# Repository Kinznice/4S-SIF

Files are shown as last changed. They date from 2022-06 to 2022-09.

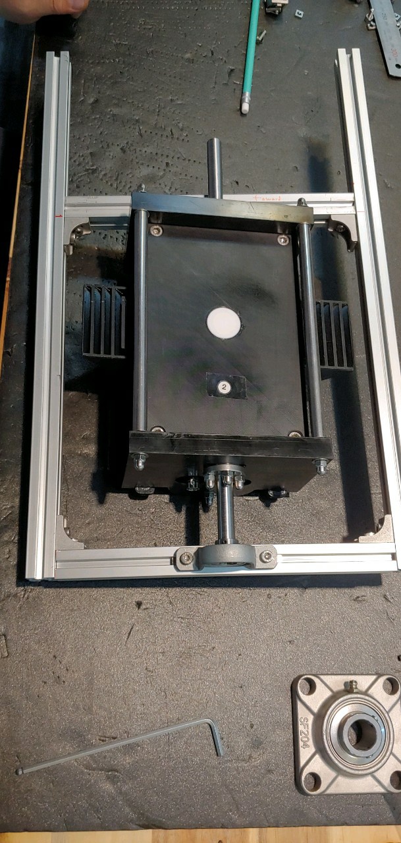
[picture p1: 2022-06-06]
Images/c10.jpg

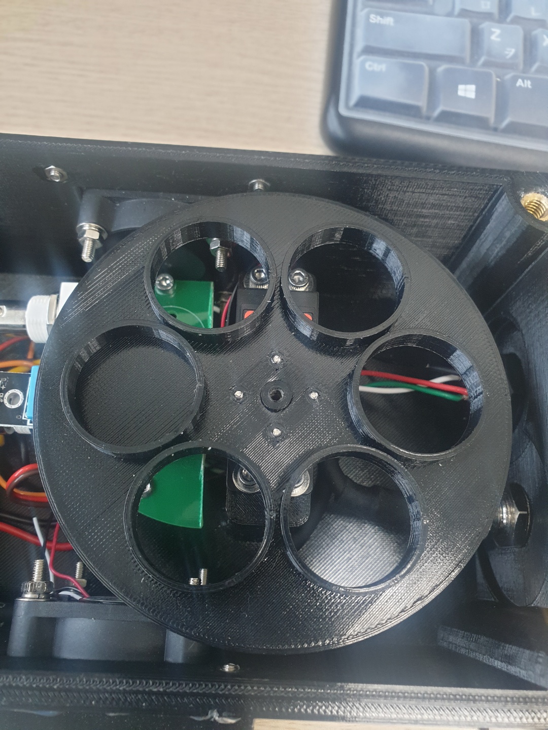
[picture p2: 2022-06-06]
Images/c11.jpg

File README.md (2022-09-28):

# Smart Surface Sensing System - for SIF version (4S-SIF)<br />
% The uploaded information for 4S-SIF.<br />

% Reference: Kim et al., XXXX % <br />

Components > Item Information<br />
3D_printer  > 3D printing Information<br />
Codes > Codes for Raspberry Pi<br />
Images > Images for 4S-SIF<br />
PCB > Customized Printed Circuit Board<br />
4S-SIF code > information about 4S code<br />

/////////////////////////////////////////////////////////////<br />
Contact information:<br /><br />

Jongmin Kim, Ph.D.<br />

Postdoc, Department of Environmental Sciences<br />
University of Virginia<br />
Clark Hall<br />
he | him | his<br />

E-mail : kinznice@gmail.com or JongminKim@virginia.edu<br />
Homepage : www.kimhyodong.com<br />
phone : 1-434-956-9619<br />

/////////////////////////////////////////////////////////////<br />

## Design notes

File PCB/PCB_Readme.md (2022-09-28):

**PCB for 4S-SIF** <br />

Please feel free to tell me if you have any questions. <br /> <br />

------------------------<br />
Jongmin Kim, PhD<br />
he | him | his<br />

E-mail : kinznice@gmail.com or JongminKim@virginia.edu<br />
Homepage : www.kimhyodong.com<br />
phone : 1-434-956-9619<br />

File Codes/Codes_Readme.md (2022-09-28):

**Codes for 4S-SIF** <br />

4S_SIF_FINAL.py = Python for Raspberry Pi to operate 4S-SIF. <br /> <br />
real_recent.sh = Shell file for image to take automatically in Raspberry Pi. <br /> <br />
servo = Python for testing servo motor in Raspberry Pi. <br /> <br />

------------------------<br />
Jongmin Kim, PhD<br />
he | him | his<br />

E-mail : kinznice@gmail.com or JongminKim@virginia.edu<br />
Homepage : www.kimhyodong.com<br />
phone : 1-434-956-9619<br />

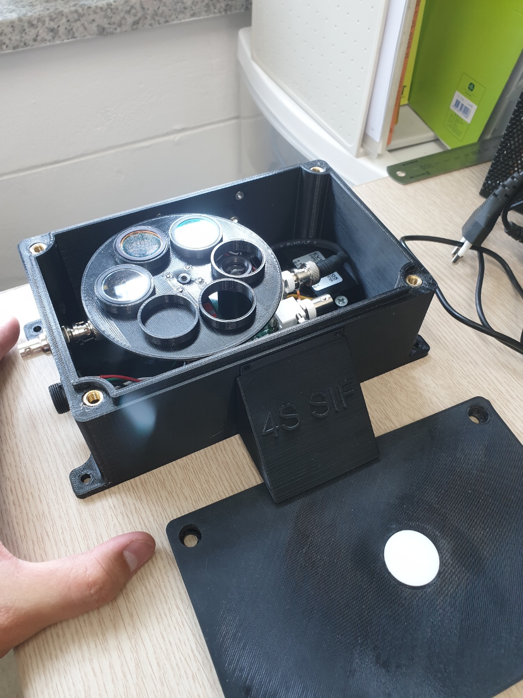
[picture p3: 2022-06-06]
Images/c1.jpg

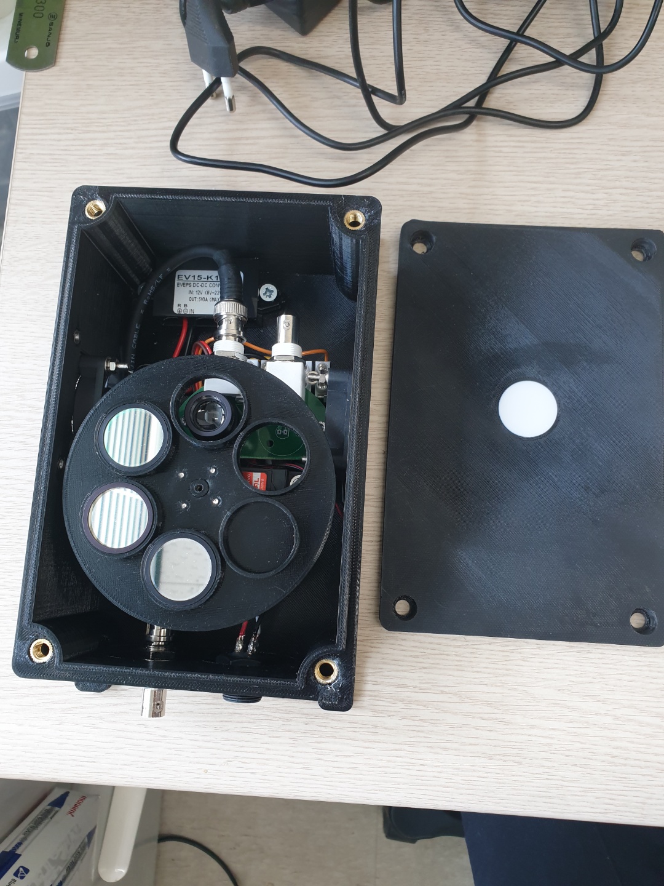
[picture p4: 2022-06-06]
Images/c4.jpg

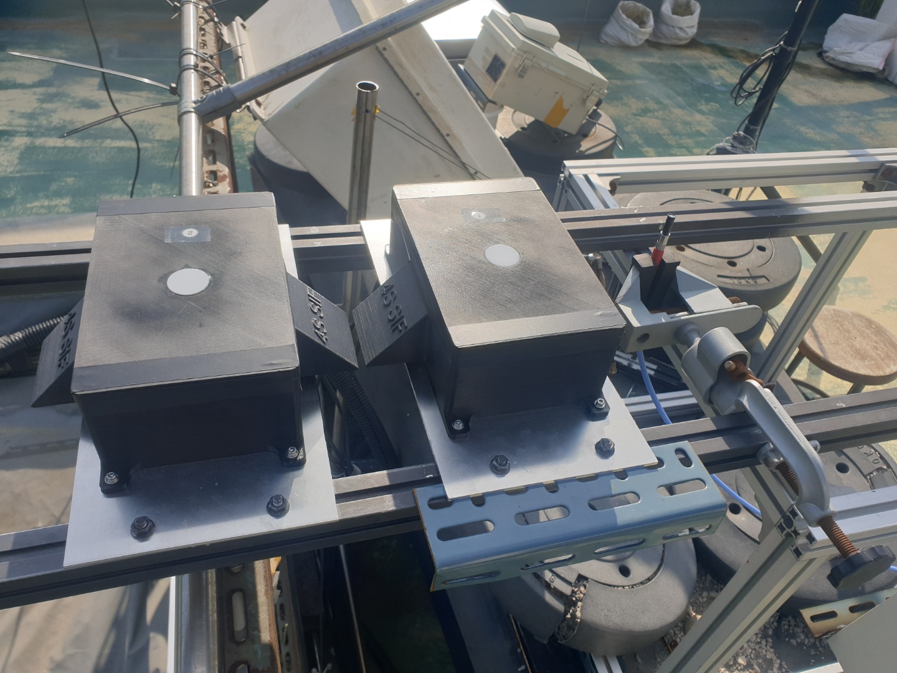
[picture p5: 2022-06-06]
Images/c6.jpg

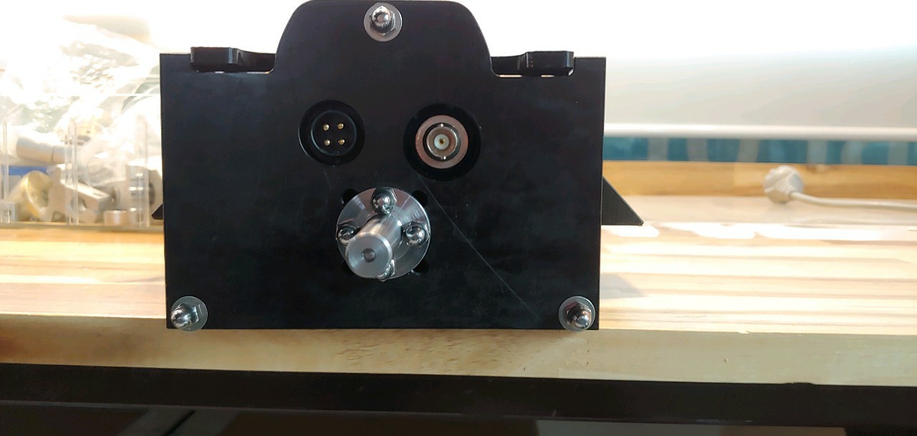
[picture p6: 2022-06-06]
Images/c8.jpg

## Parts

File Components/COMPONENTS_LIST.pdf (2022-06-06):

Appendix. A Components list. Prices as of 2020 - 2021 at South Korea.

Table A1) Components list

Component | Item | Company | Q’ty | Unit price (USD)
Photodiode | S2386-18K | Hamamatsu Photonics | 1 | $ 1.88
Photosensor amplifier | C9329 | Hamamatsu Photonics | 1 | $ 1298
Diffuser | White diffusing glass | Edmund Optics | 1 | $ 43.5
Collimating lens | LA1540-ML | Thorlabs | 1 | $ 38.55
Ultra-narrow bandpass filter for 757 nm | 757.9-1 OD4 | Alluxa | 1 | $ 1160.7
Ultra-narrow bandpass filter for 761 nm | 760.7-1 OD4 | Alluxa | 1 | $ 910
Bandpass filter for 761 nm | 745BP70 | Omega Optical | 1 | $ 409.67
Ultra-narrow bandpass filter for 770 nm | 770NB | Omega Optical | 1 | $ 329
Geared motor | GGM DC 12V 3000rpm | GGM | 1 | $ 49.16
Servomotor | PDI-6225MG-300 | JX | 1 | $ 2.46
Microcomputer | Raspberry Pi b3 module | Raspberry Pi foundation | 1 | $ 41
Temperature and humidity sensor | DHT22 | Adafruit | 1 | $ 0.33
Fan | DC brushless | Jameco electronics | 2 | $ 21.6
Micro SD card 16GB | SD card | Samsung | 1 | $ 17.2
For 3D Structure | PET material | - | 1 | $ 20.5
Sum | | | | $ 4343.55

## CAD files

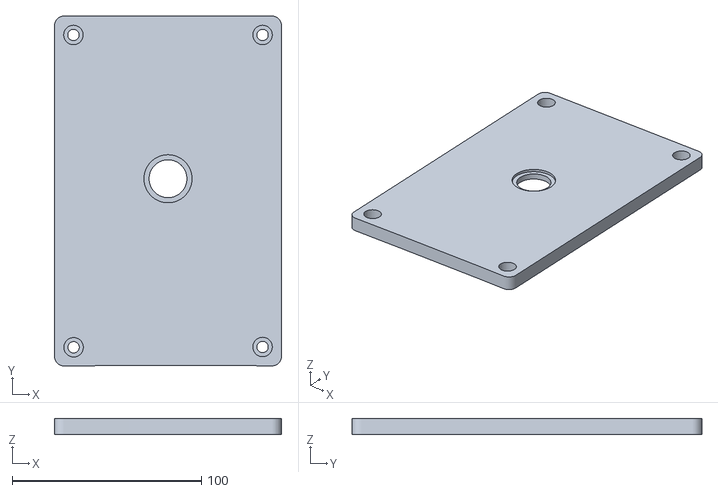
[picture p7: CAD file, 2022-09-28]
3D_printer/Final_V/Main_cap.stl
120.0 x 185.0 x 8.50

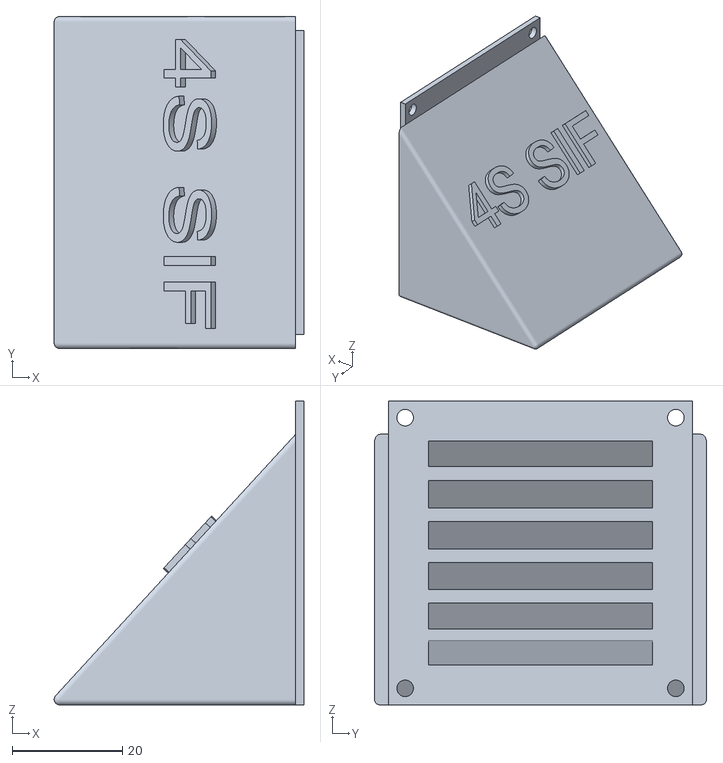
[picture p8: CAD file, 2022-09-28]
3D_printer/Final_V/Cap_fan.stl
45.2 x 60.1 x 55.0

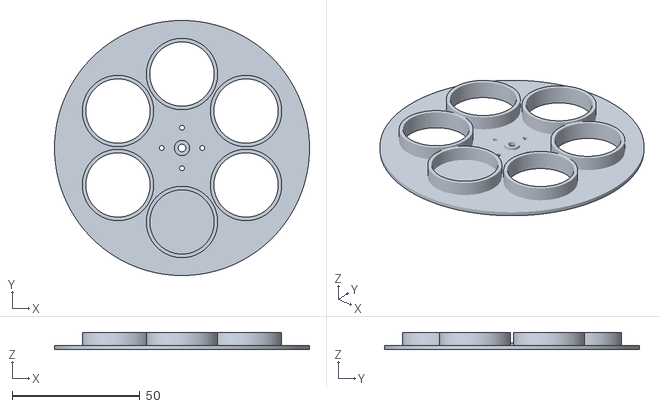
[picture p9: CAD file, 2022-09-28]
3D_printer/Final_V/Filter_body.stl
100.0 x 100.0 x 6.70

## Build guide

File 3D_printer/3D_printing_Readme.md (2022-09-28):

**3D Printed structure** <br />

V1 = 2018 year version. We measured 755, 760, 770 nm seperately by using three photodiodes. <br /> <br />
V2 = 2019 year version. We changed overall structure to remove light leakage. <br /> <br />
V3 = 2020 year version. We changed PCB to reduce dark current fluctuation. <br /> <br />
Final V = 2021 year version. We tried to meausre 755, 760, 770 nm using one photodiode. <br /> <br />

------------------------<br />
Jongmin Kim, PhD<br />
he | him | his<br />

E-mail : kinznice@gmail.com or JongminKim@virginia.edu<br />
Homepage : www.kimhyodong.com<br />
phone : 1-434-956-9619<br />

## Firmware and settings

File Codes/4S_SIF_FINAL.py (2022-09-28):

## Import codes ## 

import RPi.GPIO as GPIO
import serial
import time
import os
import base64
from datetime import datetime
import Adafruit_DHT

## Set GPIO ##
GPIO.setwarnings(False)
GPIO.setmode(GPIO.BCM)

## Set motor location for Filter numbers ##
filters = {
    2:75, ## For 755 nm filter
    4:76, ## For 760 nm filter
    6:77, ## For 770 nm filter
    8:00,
    10:11,
    12:12
}

SERVO_PIN = 18  ## Set servo motor GIO PIN
TEMP_PIN = 23  ## Set Temp/Humi sensor GIO PIN

DHT22 = Adafruit_DHT.AM2302 ## Set Temp/Humi sensor

sw_L  = 6 ## Setting for geared motor
sw_R  = 5 ## Setting for geared motor
pwmL = 13 ## Setting for geared motor
pwmR = 12 ## Setting for geared motor

## Set GPIO ##
GPIO.setup(SERVO_PIN, GPIO.OUT)
GPIO.setup(sw_L,GPIO.IN)
GPIO.setup(sw_R,GPIO.IN)
GPIO.setup(pwmL,GPIO.OUT)
GPIO.setup(pwmR,GPIO.OUT)

##updown motor speed
dcspeed =50      

print("Warming Up ...")
for cnt in range(40):
    print(40-cnt ," ...")
    time.sleep(1)

## Saved file directory ##
sTime = time.strftime('%Y_%m_%d_%H_%M_%S',time.localtime(time.time()))
#print(sTime)
# File URL
url = '/home/pi/4S_SIF_v2/FS_SIF_v2_%s.txt' % (sTime)

## Geard motor setting ##
pwm = GPIO.PWM(SERVO_PIN,50)
pwm.start(2)

pwm_L = GPIO.PWM(pwmL,100)
pwm_R  = GPIO.PWM(pwmR,100)

pwm_R.start(dcspeed)
pwm_L.start(dcspeed)

## Set Temp/Humi sensor ##
humidity,temperature = 0.0,0.0
updown = 0

extraTag = "Temp= {0:0.1f} C , Humi= {1:0.1f} % ".format(temperature, humidity)

## Setting for Photodiode ADC ##
ser = serial.Serial(
    port = '/dev/ttyUSB_P1',
    baudrate = 19200,
    timeout = 1,
    parity = serial.PARITY_NONE,
    stopbits = serial.STOPBITS_TWO,
    bytesize = serial.EIGHTBITS
)
    
line = []
cc = " "
pos = 2
k = 2.4
log = " "

fn = datetime.now().strftime("%Y%m%d-%H%M%S" + ".txt")
sday = datetime.now().day

##updown Motor Set Left
if GPIO.input(sw_L) == 0:
    pwm_R.ChangeDutyCycle(dcspeed)
    pwm_L.ChangeDutyCycle(0)
    time.sleep(2)
    

pwm_R.ChangeDutyCycle(0)
pwm_L.ChangeDutyCycle(dcspeed)
while GPIO.input(sw_L):
    time.sleep(0.05)
pwm_L.ChangeDutyCycle(0)


## Main body for data collection ##
time.sleep(10)
while True:
    today = datetime.now().day
    if sday != today:
       sday = today
       fn = datetime.now().strftime("%Y%m%d-%H%M%S" + ".txt") 
    try:        
        pwm.ChangeDutyCycle(k)
        if pos > 3:
            time.sleep(2)
            pwm.ChangeDutyCycle(0)
        else:
            time.sleep(2)
            pwm.ChangeDutyCycle(0)
            
        cntTime = time.perf_counter()
        cntTarget = cntTime + 1
        while cntTime  < cntTarget:
            
            cc = str(ser.readline())            
            pp= cc.split(',')
            
            timeTaken = datetime.fromtimestamp(time.time())            
            voltage = round(int(pp[0][3:7],16) * ( 5.0 / int(pp[1][0:4],16)),6)        
            
            ###      timeTaken              Filter             Voltage            Raw
            log = str(timeTaken)  + "," + str(filters[pos]) + "," + str(voltage ) + "," + "rw:" + "," + (pp[0][3:7]) + "," + (pp[1][0:4] ) + "," +  str(int(pp[0][3:7],16)) + "," +  str(int(pp[1][0:4],16)) + ", " + "Updown: " + str(updown) + "," +  extraTag
            
            print(log )
                        
            with open(url,"a") as f:
                f.write(log + "\n")
                
            #time.sleep(0.048)
                
            cntTime = time.perf_counter()           
        
        
        if pos == 8 :
            pos  = 2
            k = 2.4

            humidity, temperature = Adafruit_DHT.read_retry(DHT22,TEMP_PIN)
            if humidity is not None and temperature is not None:
                print("UpDown : ", updown, " Temp={0:0.1f} C Humidity={1:0.1f}%".format(temperature, humidity))
                if humidity < 100 :
                    extraTag = "Temp: {0:0.1f} C , Humi: {1:0.1f} %".format(temperature, humidity)
            else:
                print("Sensor failure, CHeck wiring. ")

            updown = ( updown + 1 ) % 2
            if updown == 0:
                pwm_R.ChangeDutyCycle(0)
                pwm_L.ChangeDutyCycle(dcspeed)
                while GPIO.input(sw_L):
                    time.sleep(0.05)
                pwm_L.ChangeDutyCycle(0)
            else:
                pwm_L.ChangeDutyCycle(0)
                pwm_R.ChangeDutyCycle(dcspeed)
                while GPIO.input(sw_R):
                    time.sleep(0.05)
                pwm_R.ChangeDutyCycle(0)  
            
            
        else:
            pos = pos + 2
            if pos == 4 :
                k = 4.4
            elif pos == 6 :
                k = 6.5
            elif pos == 8 :
                k = 8.5
        
    except:
        print(cc)
        print('Serial Communication Error')
        
        
pwm.stop()
GPIO.cleanup()

##        
##            ##temperature, upDown
##            humidity, temperature = Adafruit_DHT.read(DHT22,TEMP_PIN)
##            if humidity is not None and temperature is not None:
##                print("UpDown : ", updown, " Temp={0:0.1f} C Humidity={1:0.1f}%".format(temperature, humidity))
##                if humidity < 100.0 :
##                    extraTag = "Updown: {0} , Temp: {1:0.1f} C , Humi: {2:0.1f} %".format(updown,temperature, humidity)
##            else:
##                print("Sensor failure, CHeck wiring. ")
##
##            updown = ( updown + 1 ) % 2
##            if updown == 0:
##                pwm_R.ChangeDutyCycle(0)
##                pwm_L.ChangeDutyCycle(dcspeed)
##                while GPIO.input(sw_L):
##                    time.sleep(0.05)
##                pwm_L.ChangeDutyCycle(0)
##            else:
##                pwm_L.ChangeDutyCycle(0)
##                pwm_R.ChangeDutyCycle(dcspeed)
##                while GPIO.input(sw_R):
##                    time.sleep(0.05)
##                pwm_R.ChangeDutyCycle(0)  
        

    
    

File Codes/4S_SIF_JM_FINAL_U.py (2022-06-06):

import spidev
import time
import sched
import os 
import serial
import numpy as np
import re
import sys

# Time interval
interval = 1
# Sleep for RCT module
time.sleep(60)
# Start time
sTime = time.strftime('%Y_%m_%d_%H_%M_%S',time.localtime(time.time()))

# Saving location
url1='/home/pi/RAW/FS_RAW_UP_%s.txt' % (sTime)
url2='/home/pi/SIF/FS_SIF_%s.txt' % (sTime)

t0 = time.localtime(time.time())        
        
while True:
    t = time.localtime(time.time())
    #if (t.tm_sec==0 or t.tm_sec==2 or t.tm_sec==4 or t.tm_sec==6 or t.tm_sec==8 or t.tm_sec==10 or t.tm_sec==12 or t.tm_sec==14 or t.tm_sec==16 or t.tm_sec==18 or t.tm_sec==20 or t.tm_sec==22 or t.tm_sec==24 or t.tm_sec==26 or t.tm_sec==28 or t.tm_sec==30 or t.tm_sec==32 or t.tm_sec==34 or t.tm_sec==36 or t.tm_sec==38 or t.tm_sec==40 or t.tm_sec==42 or t.tm_sec==44 or t.tm_sec==46 or t.tm_sec==48 or t.tm_sec==50 or t.tm_sec==52 or t.tm_sec==54 or t.tm_sec==56 or t.tm_sec==58):
    if (t.tm_sec>=0) :
  
        ser = serial.Serial('/dev/ttyUSB0', 57600, timeout = 1)
        ser.close()
        ser.open()

        com1 = "#RS2\n"
        com2 = "#RS1\n" 
        
        time.sleep(0.2)
        ser.write(bytes(com1.encode()))
        time.sleep(0.2)
        dresponse1 = ser.readline()
        
        dstr1=str(dresponse1)
        dstr2=','
        dstr3="'"
        dstr4='n'
        dlag2=[m.start () for m in re.finditer(dstr2, dstr1)]
        #print(dresponse1)
        #print(dlag2)
        if not dlag2:
            print('Upward Sensor is disconnected')
            #os.system('sudo reboot')
        dlag3=[m.start () for m in re.finditer(dstr3, dstr1)]
        dlag4=[m.start () for m in re.finditer(dstr4, dstr1)]
        #dtemp1=dlag3[0]+1
        #dtemp2=dlag2[0]+1
        #dtemp3=dlag3[0]-1

        da75=dstr1[dlag2[1]+1:dlag2[2]]
        da76=dstr1[dlag2[2]+1:dlag2[3]]
        da77=dstr1[dlag2[3]+1:dlag4[0]-1]
        #print(da75,da76,da77)
        
        time.sleep(0.2)
        ser.write(bytes(com1.encode()))
        time.sleep(0.2)
        uresponse1 = ser.readline()
        
        ustr1=str(uresponse1)
        ustr2=','
        ustr3="'"
        ustr4='n'
        ulag2=[m.start () for m in re.finditer(ustr2, ustr1)]
        if not ulag2:
            print('Upward Sensor is disconnected')
            #os.system('sudo reboot')
        ulag3=[m.start () for m in re.finditer(ustr3, ustr1)]
        ulag4=[m.start () for m in re.finditer(ustr4, ustr1)]

        ua75=ustr1[ulag2[1]+1:ulag2[2]]
        ua76=ustr1[ulag2[2]+1:ulag2[3]]
        ua77=ustr1[ulag2[3]+1:ulag4[0]-1]
        #print(ua75,ua76,ua77)

        darr1=np.array(da75,np.float)
        darr2=np.array(da76,np.float)
        darr3=np.array(da77,np.float)

        D75=np.mean(darr1)
        D76=np.mean(darr2)
        D77=np.mean(darr3)
        
        uarr1=np.array(ua75,np.float)
        uarr2=np.array(ua76,np.float)
        uarr3=np.array(ua77,np.float)

        U75=np.mean(uarr1)
        U76=np.mean(uarr2)
        U77=np.mean(uarr3)
        
        file1=open(url1,'a')
        #file1.write('%s, w756: %10.2f, w760: %10.2f, w770: %10.2f\n' % (time.strftime('%Y-%m-%d %H:%M:%S',t), date756, date760, date770))
        print('%s, U75: %s, U76: %s, U77: %s, U75: %s, U76: %s, U77: %s\n' % (time.strftime('%Y-%m-%d %H:%M:%S',t), U75, U76, U77, D75, D76, D77))
        file1.write('%s, U75: %s, U76: %s, U77: %s, U75: %s, U76: %s, U77: %s\n' % (time.strftime('%Y-%m-%d %H:%M:%S',t), U75, U76, U77, D75, D76, D77))
        file1.close()
    
        t0 = t
        time.sleep(0.2)
        
s = sched.scheduler(time.time, time.sleep)

# Set start time
timestamp = time.mktime(time.strptime(sTime,'%Y_%m_%d_%H_%M_%S'))

# Start
s.enterabs(timestamp, 1, do, ())
s.run()

    
  
